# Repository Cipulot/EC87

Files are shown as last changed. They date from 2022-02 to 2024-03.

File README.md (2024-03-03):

# EC87

## **DEPRECATED**

This project has been deprecated in favor of the next TKL I'm working on.
It will not be updated nor maintained from now on, so do no base projects, them being PCB or cases, on it.
The project of reference for EC TKL will be named (provisional for now, in search of a better name still): ECip TKL
This new design will join the EC60 in the reference design family of PCBs that I'm working on. Think of these as the EC equivalent of the H87/88 and H60 for MX switches. An FRL will be developed too, to complete the general layouts. Both will feature the same key and cluster spacing as the H87/88 PCBs, so that future design of cases can have both MX and EC options without compromising compatibility or having to develop separate cases/parts of cases for it.

## Introduction

EC87 is an Electrostatic Capacitive (EC) TKL keyboard PCB.

This project is a continuation of my development of open source EC boards after publishing the [Corne EC Revival](https://github.com/Cipulot/CorneECRevival).

Below is the KLE of the supported layout:

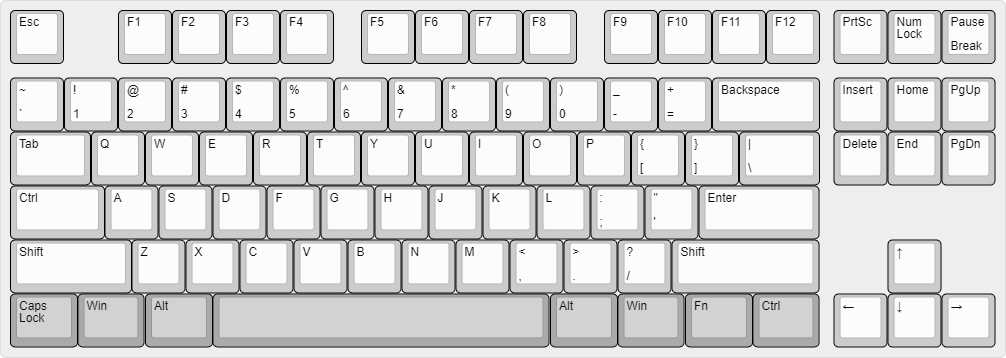
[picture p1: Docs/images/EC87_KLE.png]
EC87 KLE


Multi layout support is planned for Rev2.

## Technical information

- Layout size: tenkeykess (TKL)
- Compatible switches: EC switches (Topre and NIZ)
- Microcontroller: STM32F411
- Connector: detachable USB Type C
- Firmware compatibility: QMK (with VIA/VIAL support)
- Protection hardware:
  - Fused
  - ESD protection

## Renders and Prototypes

### EC87 PCB

#### Render

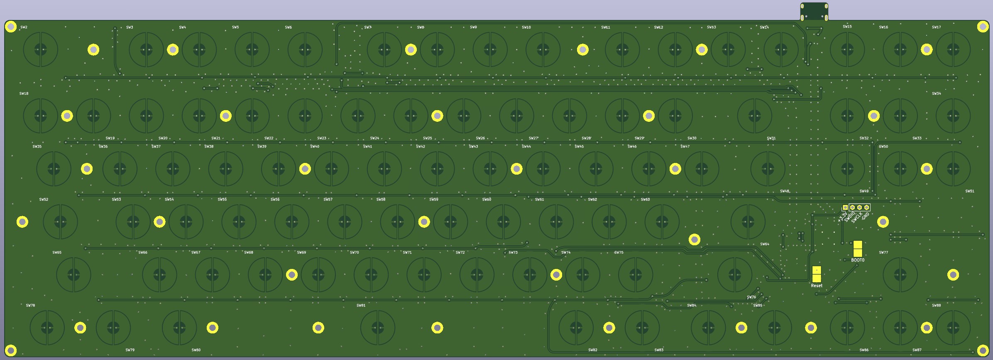
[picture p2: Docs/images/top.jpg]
EC87 PCB Top Render


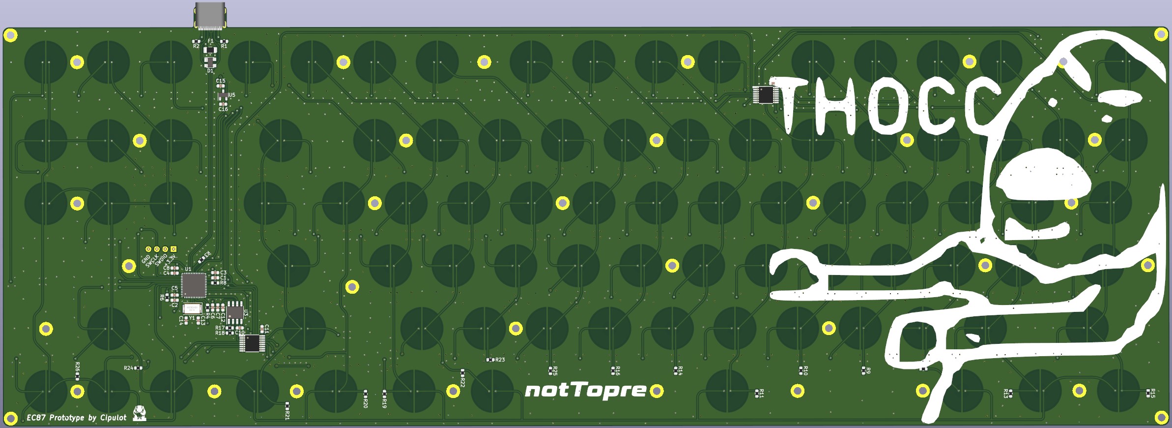
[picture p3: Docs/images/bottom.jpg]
EC87 PCB Bottom Render


#### Prototype

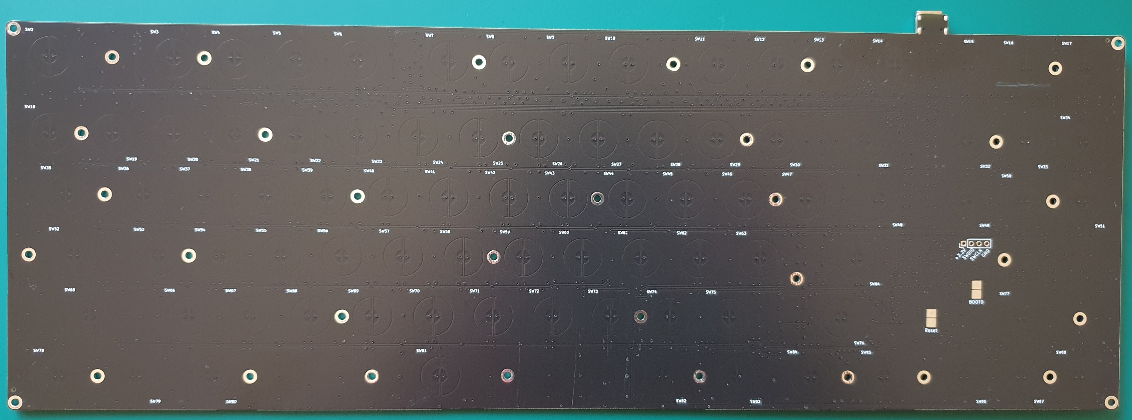
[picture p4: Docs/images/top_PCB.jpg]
EC87 PCB Top Proto


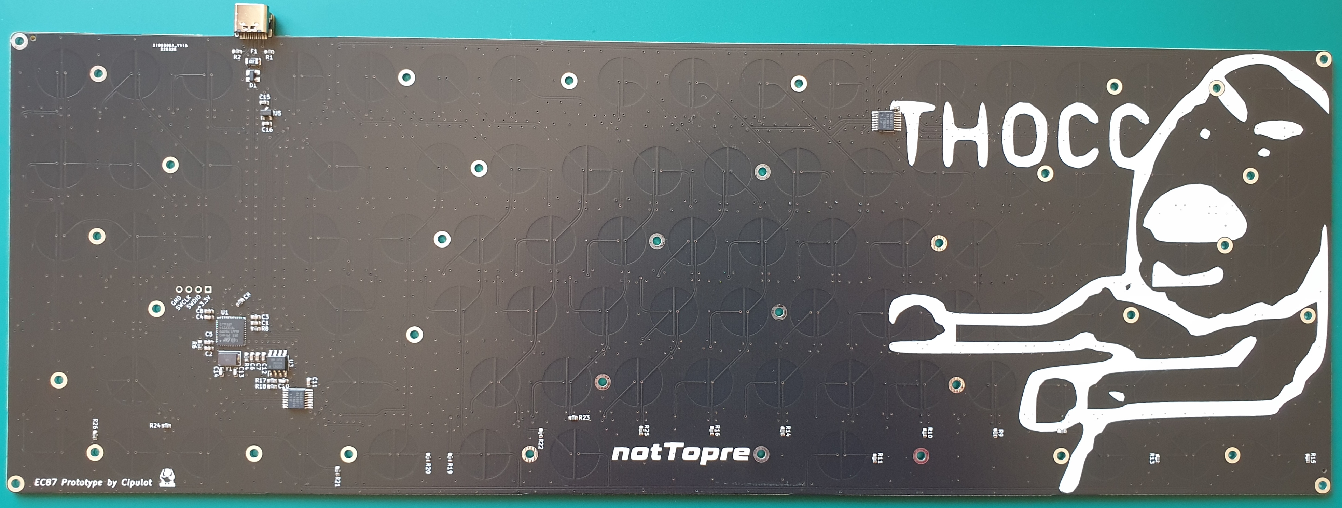
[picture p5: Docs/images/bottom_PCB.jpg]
EC87 PCB Bottom Proto


### Plate

#### Render

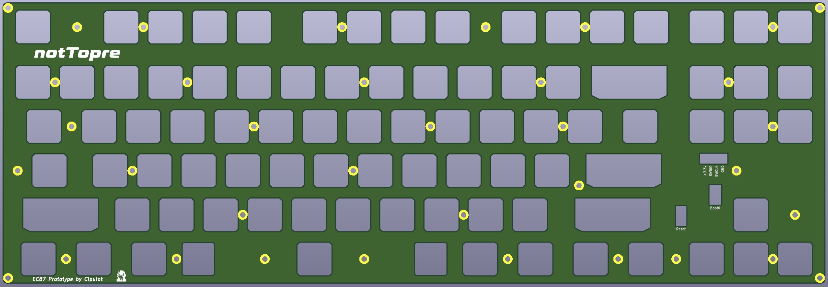
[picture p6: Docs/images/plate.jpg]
EC87 Plate Render


#### Prototype

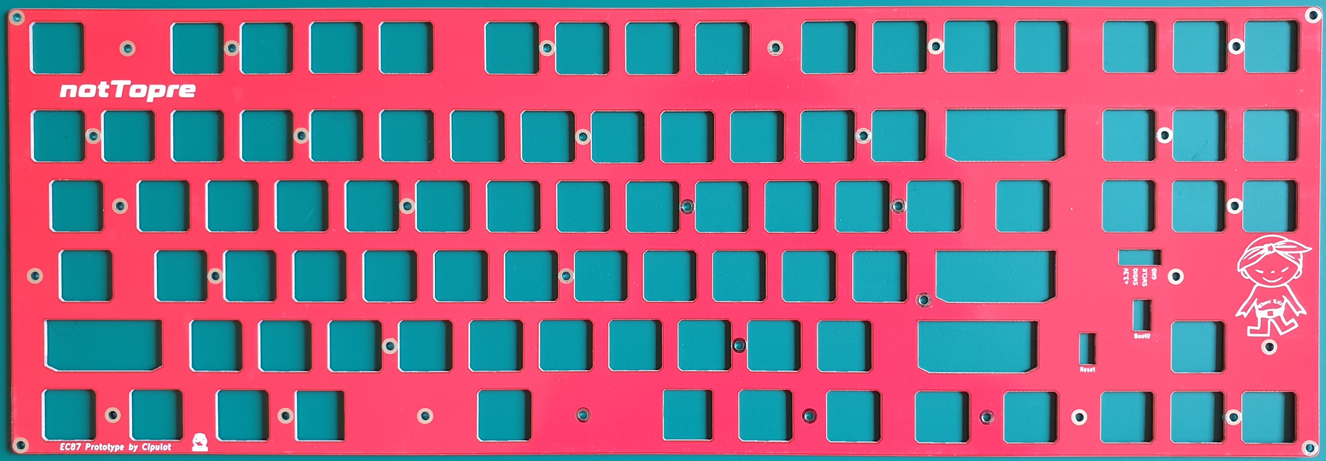
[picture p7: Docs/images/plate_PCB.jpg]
EC87 Plate Proto


### Backplate

#### Render

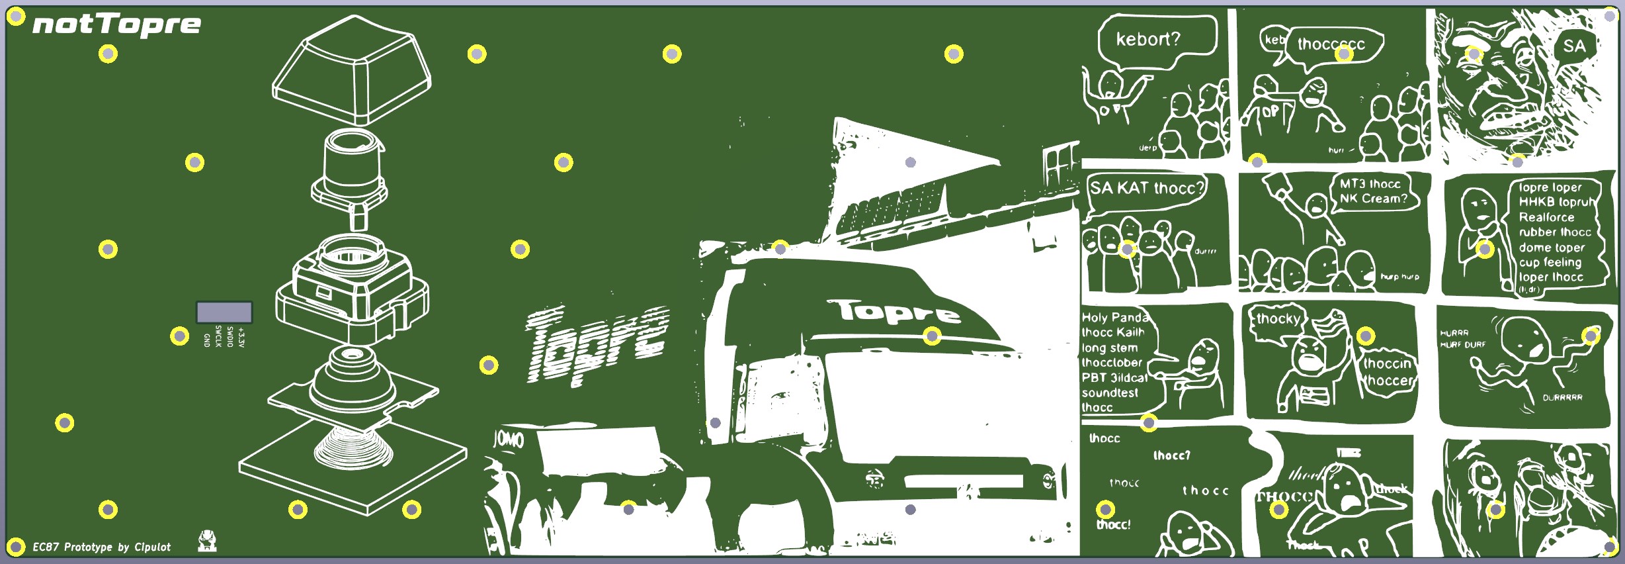
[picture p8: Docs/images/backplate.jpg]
EC87 Backplate Render


#### Prototype

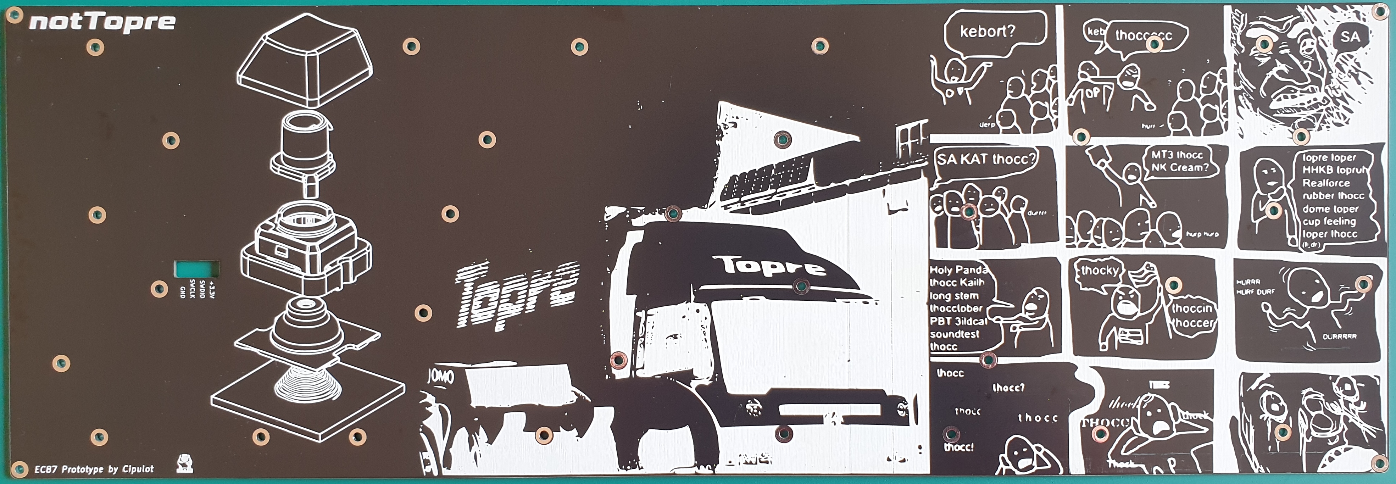
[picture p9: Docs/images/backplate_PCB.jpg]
EC87 Backplate Proto


## Revisions and relative features

### Rev1

First revision of the board used for validation purposes of the circuit and QMK software.

Features include:

- Extension of the analog sensing circuit used in Corne EC Revival

- STM32F411 MCU for better performance, both cycle wise and in ADC performance compared to 32U4

- APC (Actuation Point Changer) with predefined actuation points and full scale analog switch control (full board / per key)

### Rev2

Rev 2 is already in the work and will have some radical changes, to allow better compatibility, layout options and performance improvements.

Features that will be included:

- Addition of multi-layout option (ANSI, ISO and different bottom rows)

- Rework of the analog circuit, basing it off a new "standard" model that is in development by [Gondolindrim](https://github.com/Gondolindrim) (absolute chad), myself and others. This so that we achieve a reliable enough design to enable more designers and more EC boards to get into the wild.

- Dedicated PCBs for specific MX boards already being run.

## WIP

Implementation of APC and initial calibration is in development. This features will allow to choose from a set op predetermined actuation points by simply cycling through them using a key combination. The initial calibration is to ensure that the overall baseline reading is equal across all the keys. Later, in Rev2, this will be used to adjust hardware gain through dedicated control circuit.

See commits in `Firmware` for details about the state of development.

## License

<br />This work is licensed under a <a rel="license" href="http://creativecommons.org/licenses/by-nc-sa/4.0/">Creative Commons Attribution-NonCommercial-ShareAlike 4.0 International License</a>.

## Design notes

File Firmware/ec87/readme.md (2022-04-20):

# EC87

EC87

EC version of the H87x TKL pcb.

* Keyboard Maintainer: [cipulot](https://github.com/cipulot)
* Hardware Supported: EC87
* Hardware Availability: TBD

Make example for this keyboard (after setting up your build environment):

    make ec87:default
    make ec87:via

Flashing example for this keyboard:

    make ec87:default:flash
    make ec87:via:flash

See the [build environment setup](https://docs.qmk.fm/#/getting_started_build_tools) and the [make instructions](https://docs.qmk.fm/#/getting_started_make_guide) for more information. Brand new to QMK? Start with our [Complete Newbs Guide](https://docs.qmk.fm/#/newbs).

## Bootloader

Enter the bootloader in 2 main ways:

* **Physical reset pins**: Short circuit the pads marked as `BOOT0` on the top of the PCB and plug in the keyboard
* **Keycode in layout**: Press the key mapped to `RESET` if it is available.

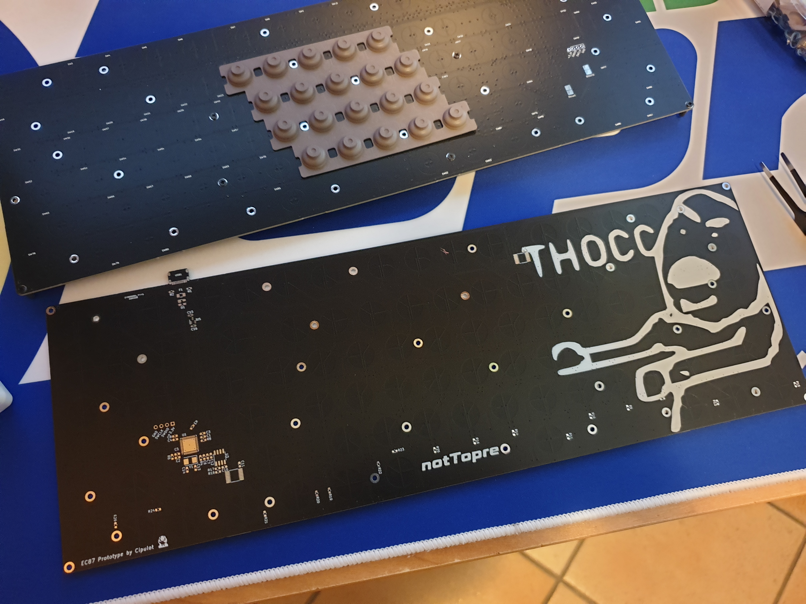
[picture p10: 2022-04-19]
Docs/images/top_bottom_together_PCB.jpg

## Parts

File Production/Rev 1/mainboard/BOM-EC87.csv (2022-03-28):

Comment | Designator | Footprint | LCSC
100k | R24 | R_0603_1608Metric | C25803
100n | C4 | C_0603_1608Metric | C14663
100k | R20 | R_0603_1608Metric | C25803
100k | R3 | R_0603_1608Metric | C25803
100k | R13 | R_0603_1608Metric | C25803
PRTR5V0U2X | D1 | SOT-143 | C2827688
100k | R12 | R_0603_1608Metric | C25803
100k | R11 | R_0603_1608Metric | C25803
0.1u | C9 | C_0603_1608Metric | C14663
100k | R19 | R_0603_1608Metric | C25803
XC6206PxxxMR | U5 | SOT-23 | C5446
74HC4051 | U4 | TSSOP16 | C5645
STM32F411CEUx | U1 | QFN-48-1EP_7x7mm_P0.5mm_EP5.6x5.6mm | C60420
100k | R26 | R_0603_1608Metric | C25803
100k | R23 | R_0603_1608Metric | C25803
100k | R21 | R_0603_1608Metric | C25803
10k | R8 | R_0603_1608Metric | C25804
74HC4051 | U2 | TSSOP16 | C5645
0.1u | C12 | C_0603_1608Metric | C14663
12p | C14 | C_0603_1608Metric | C38523
100k | R25 | R_0603_1608Metric | C25803
1u | C16 | C_0603_1608Metric | C15849
220p | C10 | C_0603_1608Metric | C302060
0.1u | C11 | C_0603_1608Metric | C14663
OPA350 | U3 | SOIC-8_3.9x4.9mm_P1.27mm | C13388
100k | R10 | R_0603_1608Metric | C25803
100n | C6 | C_0603_1608Metric | C14663
10k | R4 | R_0603_1608Metric | C25804
100n | C3 | C_0603_1608Metric | C14663
100k | R17 | R_0603_1608Metric | C25803
500mA | F1 | Fuse_1206_3216Metric | C70076
100k | R9 | R_0603_1608Metric | C25803
TYPE-C-31-M-12 | USB1 | HRO-TYPE-C-31-M-12-Assembly | C165948
8MHz | Y1 | Crystal_SMD_5032-2Pin_5.0x3.2mm | C390781
100k | R22 | R_0603_1608Metric | C25803
100k | R16 | R_0603_1608Metric | C25803
10k | R6 | R_0603_1608Metric | C25804
100n | C5 | C_0603_1608Metric | C14663
12p | C13 | C_0603_1608Metric | C38523
5.1k | R1 | R_0603_1608Metric | C23186
100k | R15 | R_0603_1608Metric | C25803
1k | R18 | R_0603_1608Metric | C21190
100k | R14 | R_0603_1608Metric | C25803
1u | C15 | C_0603_1608Metric | C15849
5.1k | R2 | R_0603_1608Metric | C23186
4.7u | C1 | C_0603_1608Metric | C19666
100n | C2 | C_0603_1608Metric | C14663
1u | C8 | C_0603_1608Metric | C15849
1u | C7 | C_0603_1608Metric | C15849

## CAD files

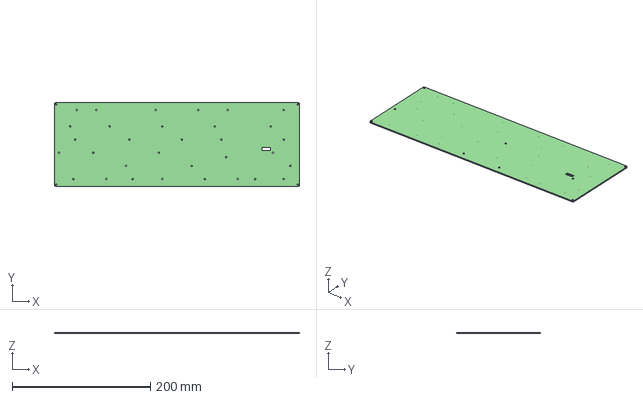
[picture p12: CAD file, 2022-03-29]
Assets/backplate.step
354.0 x 121.0 x 1.60 mm

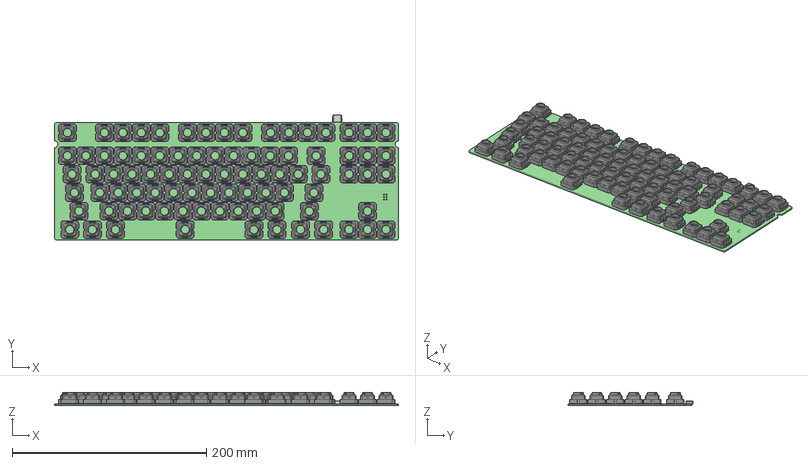
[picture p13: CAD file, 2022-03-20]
PCB/EC87.step
354.0 x 128.5 x 13.4 mm
EC87 PCB

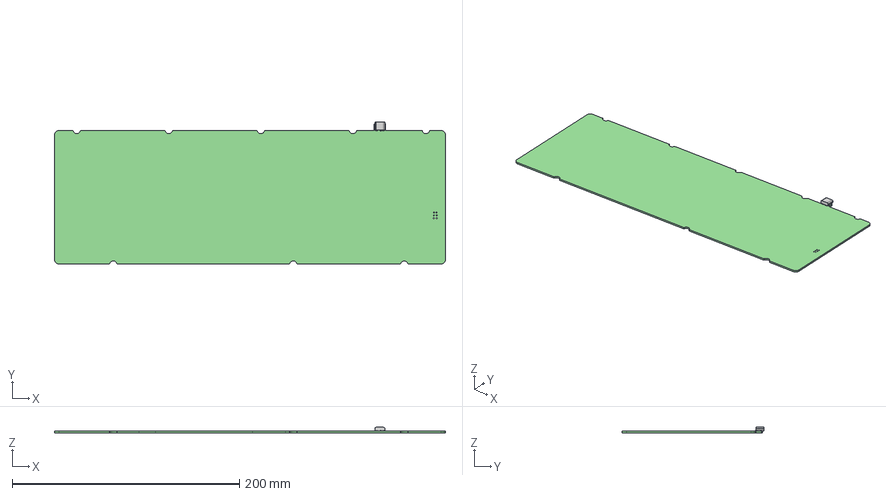
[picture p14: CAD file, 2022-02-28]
step/EC87.step
344.0 x 125.1 x 4.86 mm
EC87 PCB

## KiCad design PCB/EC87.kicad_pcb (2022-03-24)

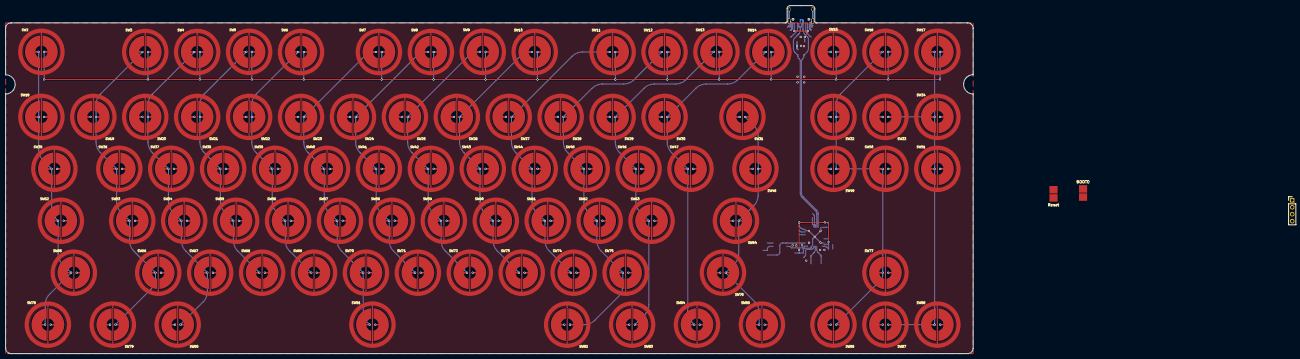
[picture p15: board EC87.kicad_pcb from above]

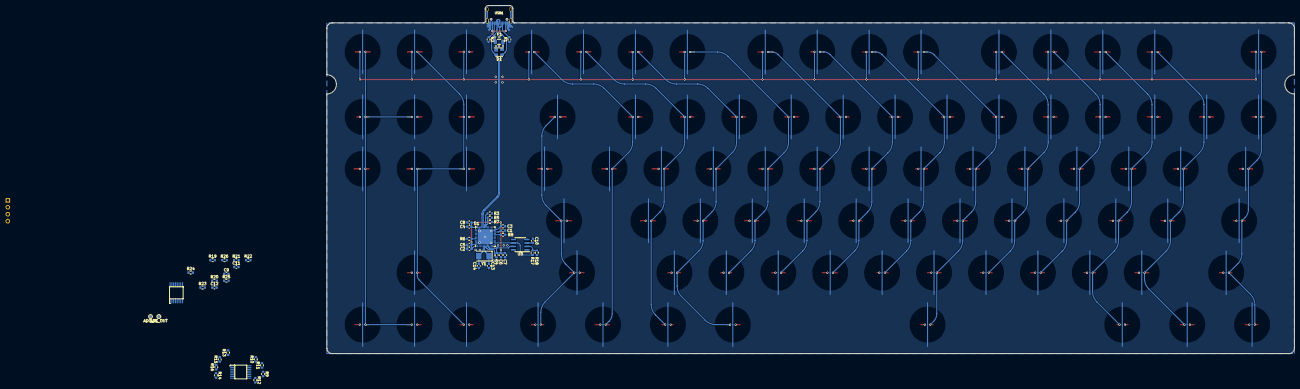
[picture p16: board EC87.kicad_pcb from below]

Board: 2 copper layers, 354.0 x 127.3 mm, 140 parts (50 on the bottom side), 46 nets.

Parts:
C1: 4.7u; C_0603_1608Metric
C2, C3, C4, C5, C6: 100n; C_0603_1608Metric
C7, C8: 1u; C_0603_1608Metric
C9, C11, C12: 0.1u; C_0603_1608Metric
C10: 220p; C_0603_1608Metric
C13, C14: 12p; C_0603_1608Metric
D1: PRTR5V0U2X; SOT-143
F1: 500mA; Fuse_1206_3216Metric
J1: SW Debug; PinHeader_1x04_P2.54mm_Vertical
R1, R2: 5.1k; R_0603_1608Metric
R3, R9, R10, R11, R12, R13, R14, R15, R16, R17, R19, R20, R21, R22, R23, R24, R25, R26: 100k; R_0603_1608Metric
R4, R5, R6, R7, R8: 10k; R_0603_1608Metric
R18: 1k; R_0603_1608Metric
SW1: BOOT0; Jumper-UserFriendly
SW2, SW3, SW4, SW5, SW6, SW7, SW8, SW9, SW10, SW11, SW12, SW13, SW14, SW15, SW16, SW17, SW18, SW19, SW20, SW21, SW22, SW23, SW24, SW25, SW26, SW27, SW28, SW29, SW30, SW31, SW32, SW33, SW34, SW35, SW36, SW37, SW38, SW39, SW40, SW41, SW42, SW43, SW44, SW45, SW46, SW47, SW48, SW49, SW50, SW51, SW52, SW53, SW54, SW55, SW56, SW57, SW58, SW59, SW60, SW61, SW62, SW63, SW64, SW65, SW66, SW67, SW68, SW69, SW70, SW71, SW72, SW73, SW74, SW75, SW76, SW77, SW78, SW79, SW80, SW81, SW82, SW83, SW84, SW85, SW86, SW87, SW88: EC_SW; ecs_pad
SW89: Reset; Jumper-UserFriendly
TP1: ADC_IN; TestPoint_Pad_D1.0mm
TP2: ADC_OUT; TestPoint_Pad_D1.0mm
U1: STM32F411CEUx; QFN-48-1EP_7x7mm_P0.5mm_EP5.6x5.6mm
U2, U4: 74HC4051; TSSOP16
U3: OPA350; SOIC-8_3.9x4.9mm_P1.27mm
USB1: HRO-TYPE-C-31-M-12; HRO-TYPE-C-31-M-12-Assembly
Y1: 8MHz; Crystal_SMD_5032-2Pin_5.0x3.2mm

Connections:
+5V: D1.4 (VCC), F1.1, R5.2
ADC: R17.1, TP2.1, U1.14 (PA4), U3.6 (OUT)
AMUX_SEL_0: U2.11 (S0), U4.11 (S0)
AMUX_SEL_1: U2.10 (S1), U4.10 (S1)
AMUX_SEL_2: U2.9 (S2), U4.9 (S2)
APLEX_OUT_PIN_0: C10.1, TP1.1, U2.3 (A), U3.3 (IN+), U4.3 (A)
BOOT0: R6.1, SW1.2 (B), U1.44 (BOOT0)
BOOT1: R8.2, U1.20 (PB2)
COL0: R15.1, SW2.1, SW18.1, SW35.1, SW52.1, SW65.1, SW78.1, U2.2 (A6)
COL1: R13.1, SW3.1, SW19.1, SW36.1, SW53.1, SW66.1, SW79.1, U2.1 (A4)
COL2: R12.1, SW4.1, SW20.1, SW37.1, SW54.1, SW67.1, SW80.1, U2.12 (A3)
COL3: R9.1, SW5.1, SW21.1, SW38.1, SW55.1, SW68.1, U2.13 (A0)
COL4: R10.1, SW6.1, SW22.1, SW39.1, SW56.1, SW69.1, U2.14 (A1)
COL5: R11.1, SW7.1, SW23.1, SW40.1, SW57.1, SW70.1, SW81.1, U2.15 (A2)
COL6: R14.1, SW8.1, SW24.1, SW41.1, SW58.1, SW71.1, U2.5 (A5)
COL7: R16.1, SW9.1, SW25.1, SW42.1, SW59.1, SW72.1, U2.4 (A7)
COL8: R25.1, SW10.1, SW26.1, SW43.1, SW60.1, SW73.1, U4.2 (A6)
COL9: R23.1, SW11.1, SW27.1, SW44.1, SW61.1, SW74.1, U4.1 (A4)
COL10: R22.1, SW12.1, SW28.1, SW45.1, SW62.1, SW75.1, SW82.1, U4.12 (A3)
COL11: R19.1, SW13.1, SW29.1, SW46.1, SW63.1, SW83.1, U4.13 (A0)
COL12: R20.1, SW14.1, SW30.1, SW47.1, SW84.1, U4.14 (A1)
COL13: R21.1, SW15.1, SW31.1, SW48.1, SW64.1, SW76.1, SW85.1, U4.15 (A2)
COL14: R24.1, SW16.1, SW32.1, SW49.1, SW50.1, SW77.1, SW86.1, U4.5 (A5)
COL15: R26.1, SW17.1, SW33.1, SW34.1, SW51.1, SW87.1, SW88.1, U4.4 (A7)
D+: D1.2 (I/O1), U1.33 (PA12), USB1.6 (DP1), USB1.8 (DP2)
D-: D1.3 (I/O2), U1.32 (PA11), USB1.5 (DN2), USB1.7 (DN1)
GND: C1.2, C2.2, C3.2, C4.2, C5.2, C6.2, C7.2, C8.2, C9.1, C10.2, C11.1, C12.1, C13.2, C14.2, D1.1 (GND), J1.4, R1.1, R2.2, R6.2, R7.1, R8.1, R9.2, R10.2, R11.2, R12.2, R13.2, R14.2, R15.2, R16.2, R18.2, R19.2, R20.2, R21.2, R22.2, R23.2, R24.2, R25.2, R26.2, SW2.3 (SG), SW3.3 (SG), SW4.3 (SG), SW5.3 (SG), SW6.3 (SG), SW7.3 (SG), SW8.3 (SG), SW9.3 (SG), SW10.3 (SG), SW11.3 (SG), SW12.3 (SG), SW13.3 (SG), SW14.3 (SG), SW15.3 (SG), SW16.3 (SG), SW17.3 (SG), SW18.3 (SG), SW19.3 (SG), SW20.3 (SG), SW21.3 (SG), SW22.3 (SG), SW23.3 (SG), SW24.3 (SG), SW25.3 (SG), SW26.3 (SG), SW27.3 (SG), SW28.3 (SG), SW29.3 (SG), SW30.3 (SG), SW31.3 (SG), SW32.3 (SG), SW33.3 (SG), SW34.3 (SG), SW35.3 (SG), SW36.3 (SG), SW37.3 (SG), SW38.3 (SG), SW39.3 (SG), SW40.3 (SG), SW41.3 (SG), SW42.3 (SG), SW43.3 (SG), SW44.3 (SG), SW45.3 (SG), SW46.3 (SG), SW47.3 (SG), SW48.3 (SG), SW49.3 (SG), SW50.3 (SG), SW51.3 (SG), SW52.3 (SG), SW53.3 (SG), SW54.3 (SG), SW55.3 (SG), SW56.3 (SG), SW57.3 (SG), SW58.3 (SG), SW59.3 (SG), SW60.3 (SG), SW61.3 (SG), SW62.3 (SG), SW63.3 (SG), SW64.3 (SG), SW65.3 (SG), SW66.3 (SG), SW67.3 (SG), SW68.3 (SG), SW69.3 (SG), SW70.3 (SG), SW71.3 (SG), SW72.3 (SG), SW73.3 (SG), SW74.3 (SG), SW75.3 (SG), SW76.3 (SG), SW77.3 (SG), SW78.3 (SG), SW79.3 (SG), SW80.3 (SG), SW81.3 (SG), SW82.3 (SG), SW83.3 (SG), SW84.3 (SG), SW85.3 (SG), SW86.2, SW86.3 (SG), SW87.3 (SG), SW88.3 (SG), SW89.2 (B), U1.8 (VSSA), U1.23 (VSS), U1.35 (VSS), U1.47 (VSS), U1.49 (VSS), U2.7 (VEE), U2.8 (GND), U3.4 (V-), U4.7 (VEE), U4.8 (GND), USB1.1 (GND), USB1.12 (GND), USB1.13 (SHIELD)
NRST: R4.2, SW89.1 (A), U1.7 (NRST)
unnamed: C1.1, U1.22 (VCAP1)
unnamed: R1.2, USB1.4 (CC1)
unnamed: R2.1, USB1.10 (CC2)
unnamed: R3.1, U1.31 (PA10)
unnamed: R17.2, R18.1, U3.2 (IN-)
PA9: R5.1, R7.2, U1.30 (PA9)
POWER_PIN: C9.2, C11.2, C12.2, U1.12 (PA2), U2.16 (VCC), U3.7 (V+), U4.16 (VCC)
ROW1: SW18.2, SW19.2, SW20.2, SW21.2, SW22.2, SW23.2, SW24.2, SW25.2, SW26.2, SW27.2, SW28.2, SW29.2, SW30.2, SW31.2, SW32.2, SW33.2, U1.38 (PA15)
ROW2: SW34.2, SW35.2, SW36.2, SW37.2, SW38.2, SW39.2, SW40.2, SW41.2, SW42.2, SW43.2, SW44.2, SW45.2, SW46.2, SW47.2, SW48.2, SW49.2, U1.39 (PB3)
ROW3: SW50.2, SW51.2, SW52.2, SW53.2, SW54.2, SW55.2, SW56.2, SW57.2, SW58.2, SW59.2, SW60.2, SW61.2, SW62.2, SW63.2, SW64.2, U1.40 (PB4)
ROW4: SW65.2, SW67.2, SW68.2, SW69.2, SW70.2, SW71.2, SW72.2, SW73.2, SW74.2, SW75.2, SW76.2, SW77.2, SW88.2, U1.41 (PB5)
ROW5: SW78.2, SW79.2, SW80.2, SW81.2, SW82.2, SW83.2, SW84.2, SW85.2, SW87.2, U1.42 (PB6)
SWCLK: J1.3, SW2.2, SW3.2, SW4.2, SW5.2, SW6.2, SW7.2, SW8.2, SW9.2, SW10.2, SW11.2, SW12.2, SW13.2, SW14.2, SW15.2, SW16.2, SW17.2, U1.37 (PA14)
SWDIO: J1.2, U1.34 (PA13)
VBAT: C2.1, C3.1, C4.1, C5.1, C6.1, C7.1, C8.1, J1.1, R3.2, R4.1, SW1.1 (A), U1.1 (VBAT), U1.9 (VDDA), U1.24 (VDD), U1.36 (VDD), U1.48 (VDD)
VBUS: F1.2, USB1.2 (VBUS), USB1.11 (VBUS)
XTAL0: C14.1, U1.5 (PH0), Y1.2
XTAL1: C13.1, U1.6 (PH1), Y1.1

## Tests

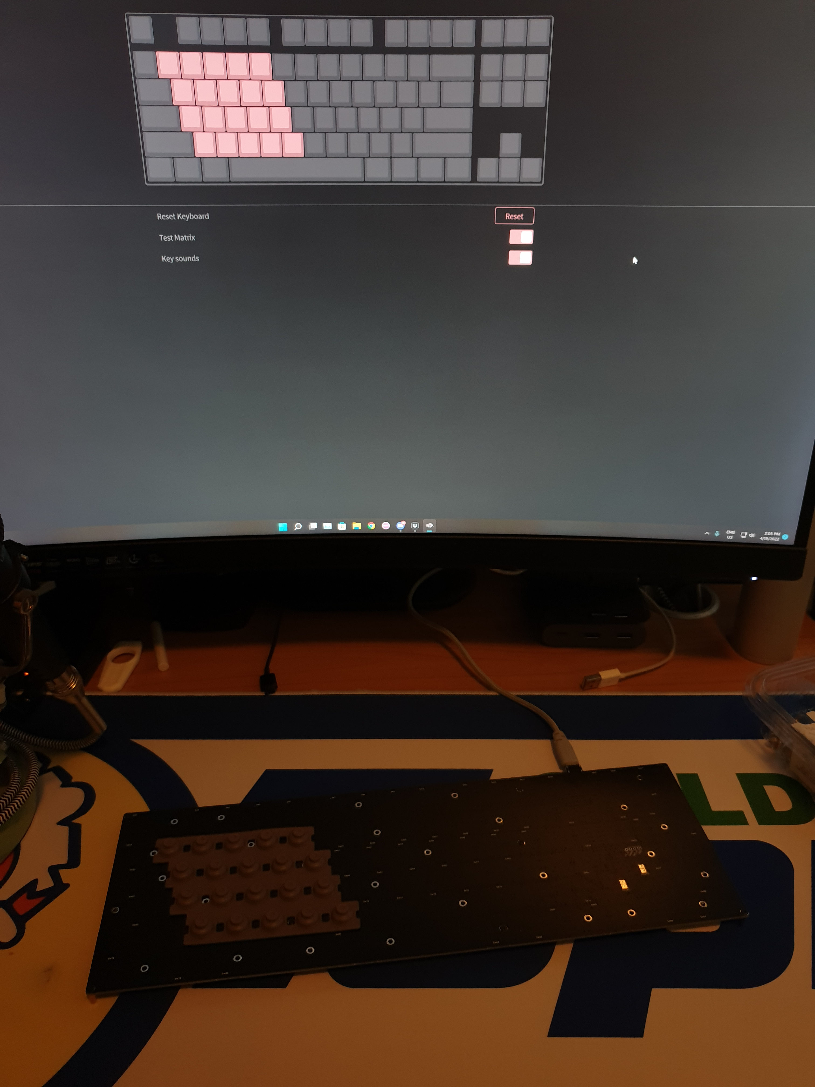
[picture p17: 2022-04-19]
Docs/images/early_test.jpg

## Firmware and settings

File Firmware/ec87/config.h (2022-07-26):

/* Copyright 2022 Cipulot
 *
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
 * You should have received a copy of the GNU General Public License
 * along with this program.  If not, see <http://www.gnu.org/licenses/>.
 */

#pragma once

/* key matrix size */
#define MATRIX_ROWS 6
#define MATRIX_COLS 16

#define LED_CAPS_LOCK_PIN A13

#define APLEX_EN_PIN_0 A8
#define APLEX_EN_PIN_1 B7
#define DISCHARGE_PIN A5
#define ANALOG_PORT_0 A2

#define MATRIX_ROW_PINS { B4, A14, A15, B3, B5, B6 }
#define MATRIX_COL_CHANNELS { 6, 4, 3, 0, 1, 2, 5, 7}
#define MUX_SEL_PINS { B0, A7, A6 }

/* COL2ROW, ROW2COL */
#define DIODE_DIRECTION COL2ROW

/* Mechanical locking support. Use KC_LCAP, KC_LNUM or KC_LSCR instead in keymap */
#define LOCKING_SUPPORT_ENABLE

/* Locking resynchronize hack */
#define LOCKING_RESYNC_ENABLE

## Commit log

2022-03-08 Update repo structure
    [EC87.kicad_pcb, EC87.kicad_sch, EC87.step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]
2022-03-08 Revert "Update repo structure"
    This reverts commit af9b34d953d0568c00315420b9b34d4b01439f36.
    [EC87.kicad_pcb, EC87.kicad_sch, EC87.step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]
2022-03-24 Firmware dump and PCB update
    [EC87.kicad_sch, analog.kicad_sch]
2022-03-26 Update final schematic and PCB
    PCB and schematic are finalized, now proceeding to addition of GND vias to shield from parasitic capacitance.
    [EC87.kicad_sch]
2022-03-27 Update of via placement
    [EC87.kicad_sch]
2022-03-28 Update of PCB for production of first proto
    [BOM-EC87.csv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]
2022-03-28 Update of plate and production folder fix
    [BOM-EC87.csv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]
2022-03-29 Added stabs cutouts
    [plate.kicad_pcb]
2022-03-29 Update for production and added backplate
    [backplate.kicad_pcb, backplate.step, plate.kicad_pcb]
2022-03-29 Update of backplate
    [backplate.kicad_pcb]
2022-03-29 Update backplate silkscreen
    [backplate.kicad_pcb]
2022-03-30 Update of schematic infos and backplate
    [EC87.kicad_sch, analog.kicad_sch, backplate.kicad_pcb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]
2022-04-05 Clean-up of docs and update firmware
    [EC87.f3d, h87a_pcb.dxf]
2022-04-11 Applied updated EC pad footprint
2022-04-12 Update plate
    [plate.kicad_pcb]
2022-04-12 Update plate 2u holes
    [plate.kicad_pcb]
2022-04-15 Update of folder structure
    [BOM-EC87.csv, EC87.kicad_sch, analog.kicad_sch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]
2022-04-16 Update to fix mounting point and add vias
2022-04-16 Update to remove logo
    [plate.kicad_pcb]
2022-04-16 Plate model update
2022-04-19 Upload images of PCB proto
2022-05-12 Added Caps Lock LED on SWDIO pin and fixed calibration
    [config.h]
2022-08-09 FIX Production files
    Fix to the production files that caused one of the 2 EC pads to be merged with the ground plane.

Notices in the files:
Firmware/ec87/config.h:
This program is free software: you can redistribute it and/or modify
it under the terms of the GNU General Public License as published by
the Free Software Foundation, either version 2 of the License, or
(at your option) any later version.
